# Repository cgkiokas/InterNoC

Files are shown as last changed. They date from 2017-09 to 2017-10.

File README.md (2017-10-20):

# InterNoC
InterNoC prototype board

### Description:
Nowadays, many embedded systems host a significant number of micro-controllers and processors (i.e. IoT devices, vehicles, airplanes, satellites) and as this number continues to increase, traditional bus solutions will start to fail on those platforms as well. Network-on-Chip (NoC) not only offer a scalable solution for MPSoC interconnects but they can also provide a uniform platform of communication to embedded systems with multiple interconnected devices.

This project aims to build an open-source FPGA-based NoC where devices can be connected to each other, transparently, enabling mixed protocol communication between multiple master / slave devices, without the need for a shared bus and at the same time allowing each device to operate in its own clock domain.

### Link to project page:
https://hackaday.io/project/27083-internoc

### Setup Notes:
All components are packed in InterNoC.lib & InterNoC.pretty so adding them in the component library and putting it in top priority should make the parts fully portable.

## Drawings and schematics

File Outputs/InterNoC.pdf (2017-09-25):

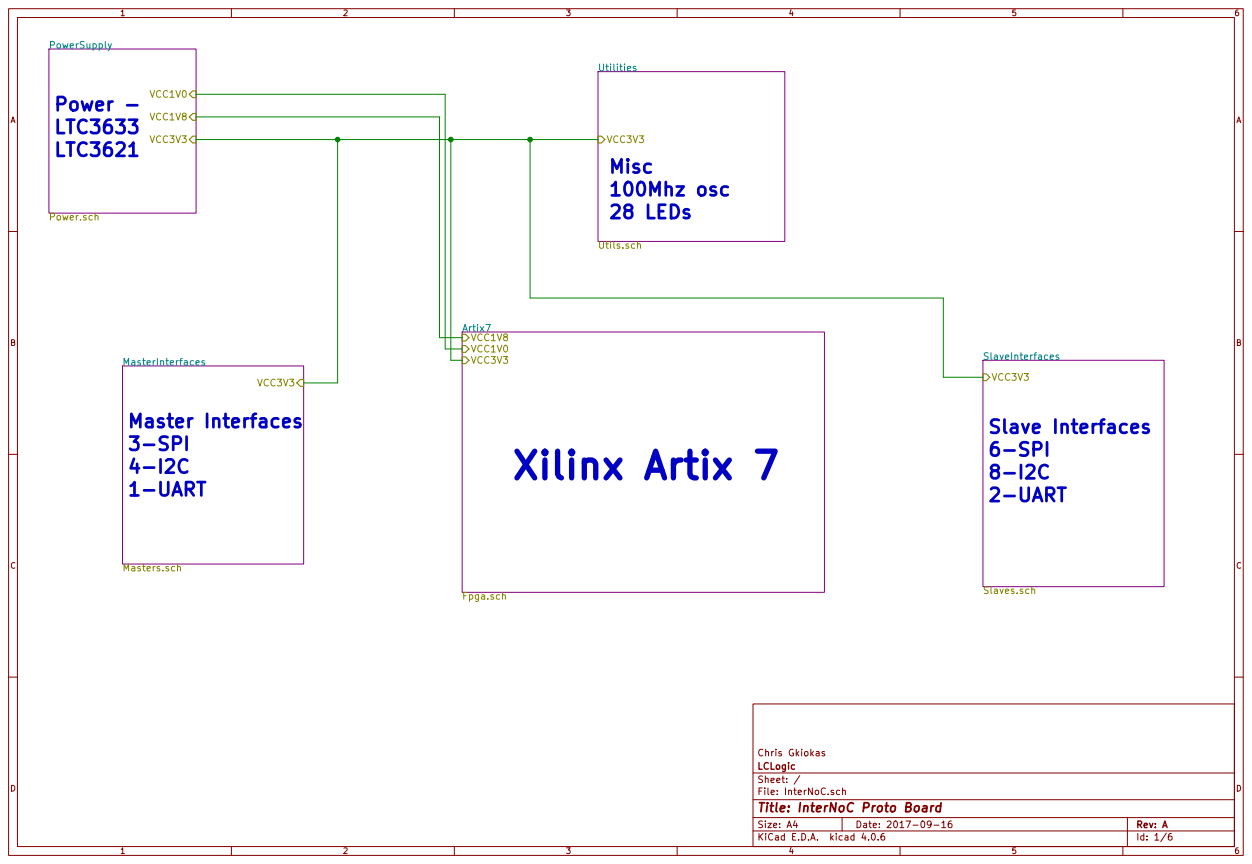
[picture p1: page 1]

Master Interfaces 4-I2C

Slave Interfaces 8-I2C

File: InterNoC.sch Sheet: / LCLogic Chris Gkiokas

Id: 1/6 Title: InterNoC Proto Board

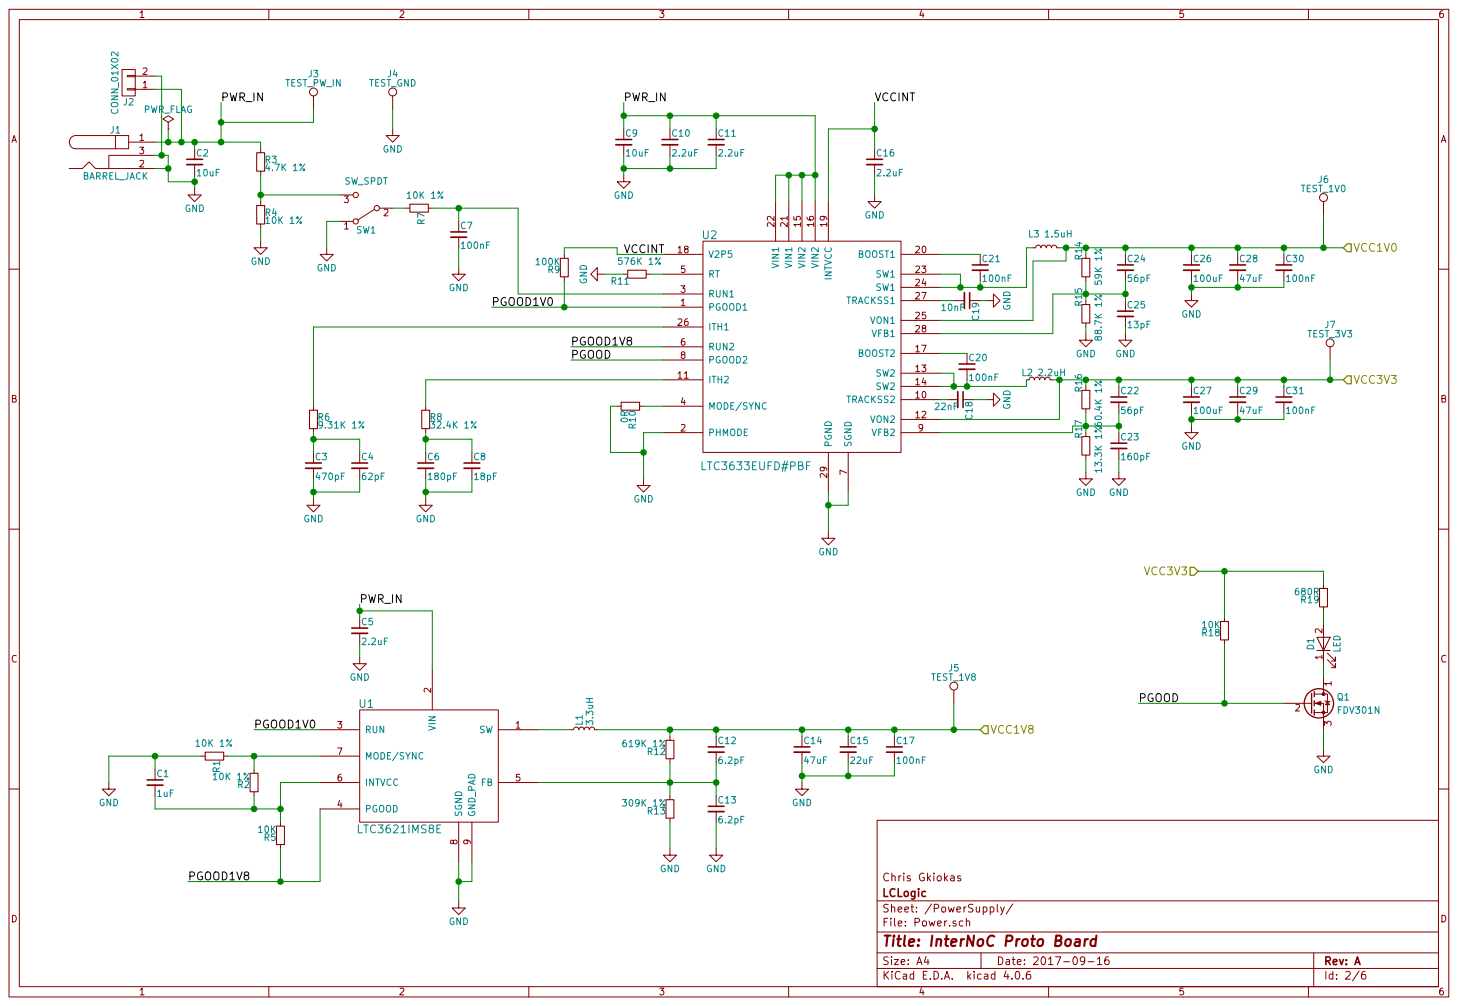
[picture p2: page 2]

File: Power.sch Sheet: /PowerSupply/
Id: 2/6 Title: InterNoC Proto Board

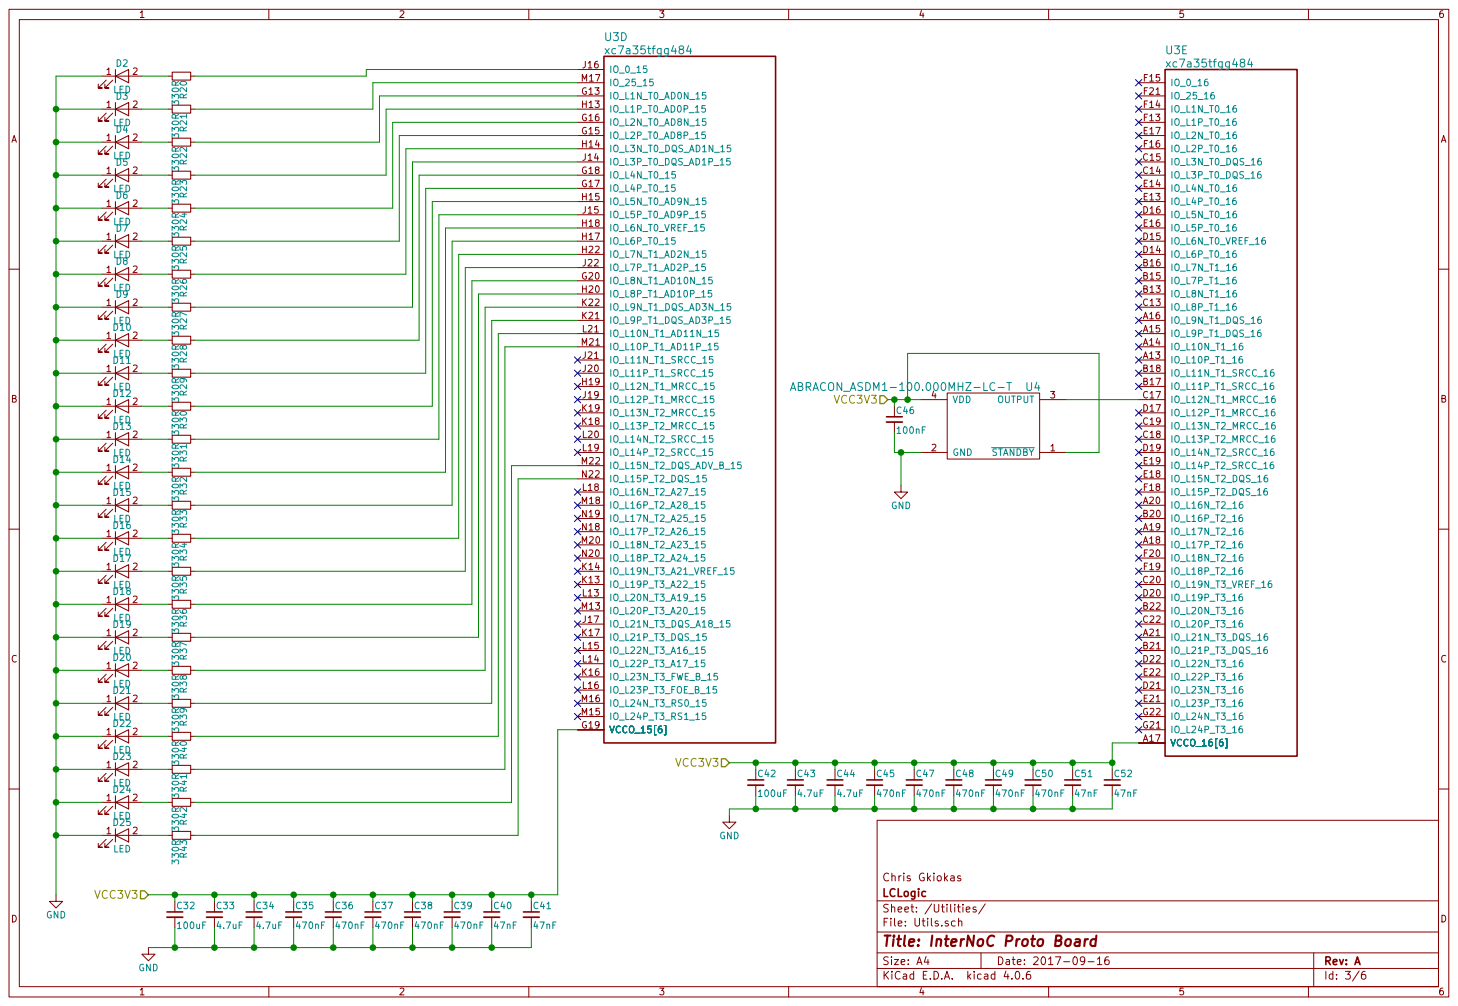
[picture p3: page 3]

File: Utils.sch Sheet: /Utilities/ LCLogic Chris Gkiokas

Id: 3/6 Title: InterNoC Proto Board

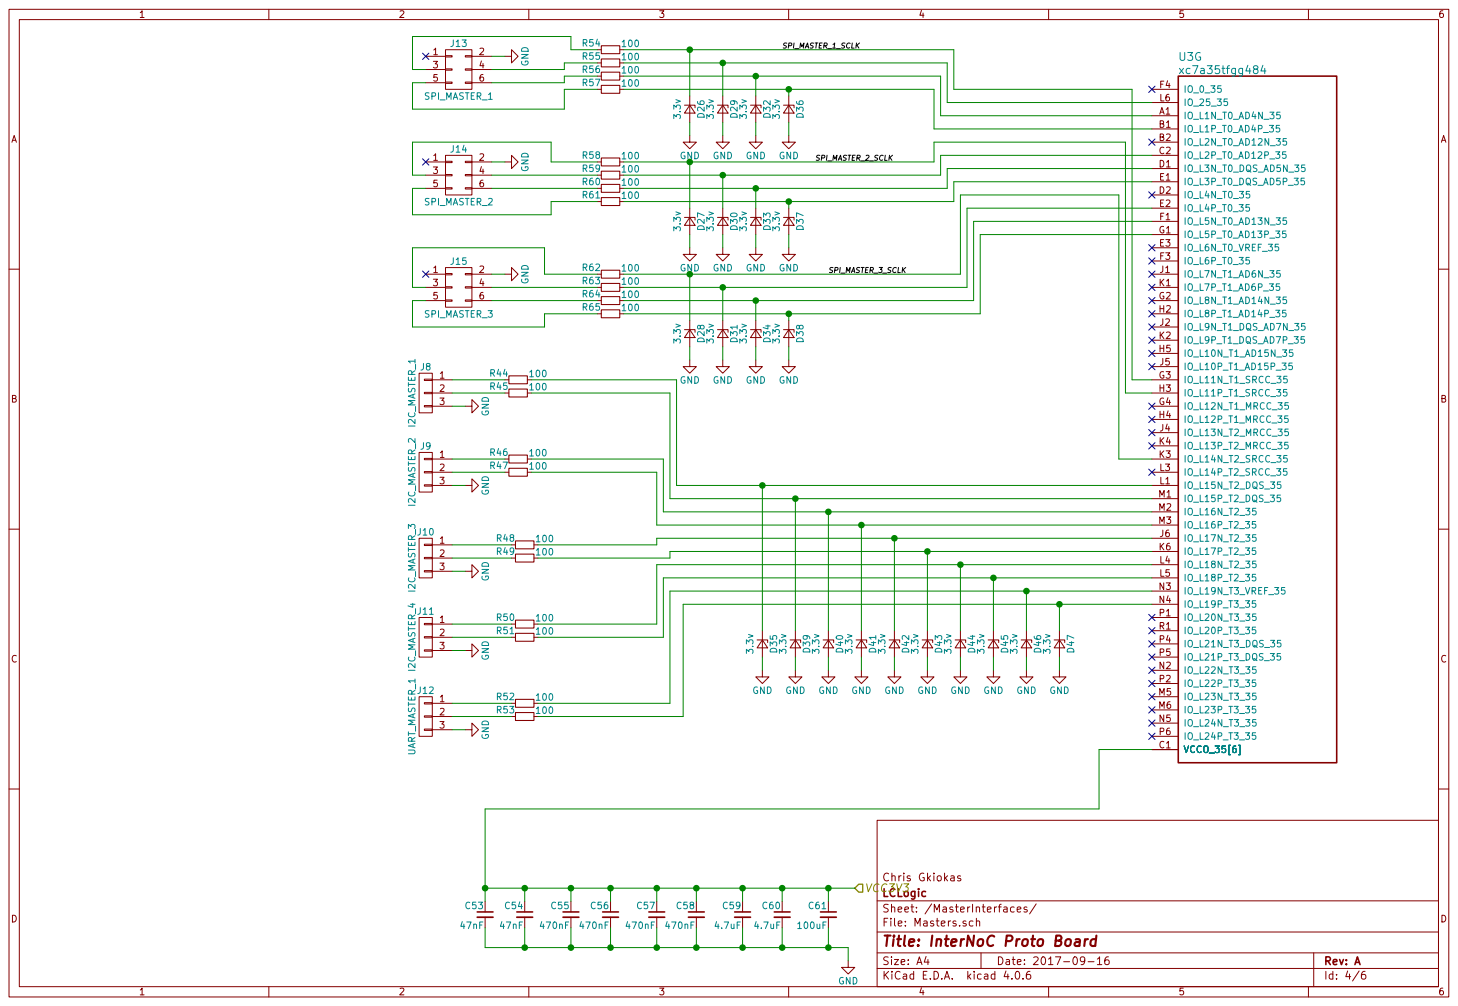
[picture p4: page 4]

IO_L1P_T0_AD4P_35 B1 VCCO_35[6] C1 IO_L6N_T0_VREF_35 E3 IO_L6P_T0_35 F3 IO_L7N_T1_AD6N_35 J1 IO_L7P_T1_AD6P_35 K1 IO_L8N_T1_AD14N_35 G2 IO_L8P_T1_AD14P_35 H2 IO_L9N_T1_DQS_AD7N_35 J2 IO_L9P_T1_DQS_AD7P_35 K2 IO_L10N_T1_AD15N_35 H5 IO_L10P_T1_AD15P_35 J5 IO_L11N_T1_SRCC_35 G3

IO_L3N_T0_DQS_AD5N_35 D1
IO_L3P_T0_DQS_AD5P_35 E1
IO_L4N_T0_35 D2

IO_L5N_T0_AD13N_35 F1
IO_L5P_T0_AD13P_35 G1

IO_L16N_T2_35 M2
IO_L16P_T2_35 M3
IO_L17N_T2_35 J6
IO_L17P_T2_35 K6

IO_L18P_T2_35 L5
IO_L19N_T3_VREF_35 N3
IO_L19P_T3_35 N4

File: Masters.sch Sheet: /MasterInterfaces/ LCLogic Chris Gkiokas

Id: 4/6 Title: InterNoC Proto Board

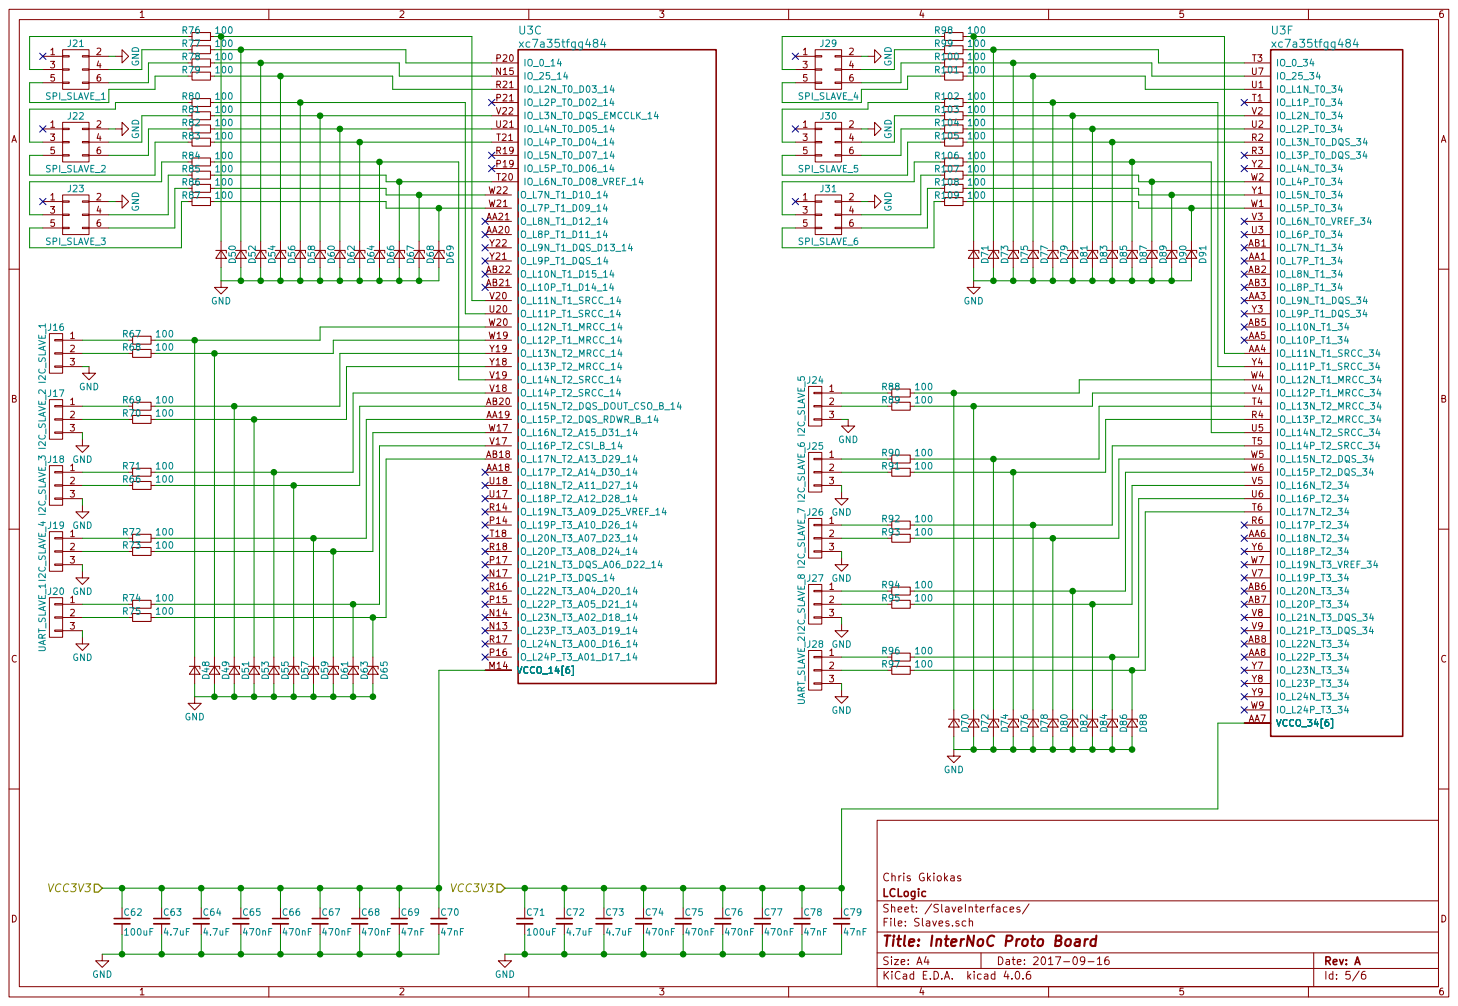
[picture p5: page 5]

IO_L5N_T0_34 Y1
IO_L5P_T0_34 W1

IO_L12P_T1_MRCC_34 V4
IO_L13N_T2_MRCC_34 T4
IO_L13P_T2_MRCC_34 R4

File: Slaves.sch Sheet: /SlaveInterfaces/ LCLogic Chris Gkiokas

Id: 5/6 Title: InterNoC Proto Board

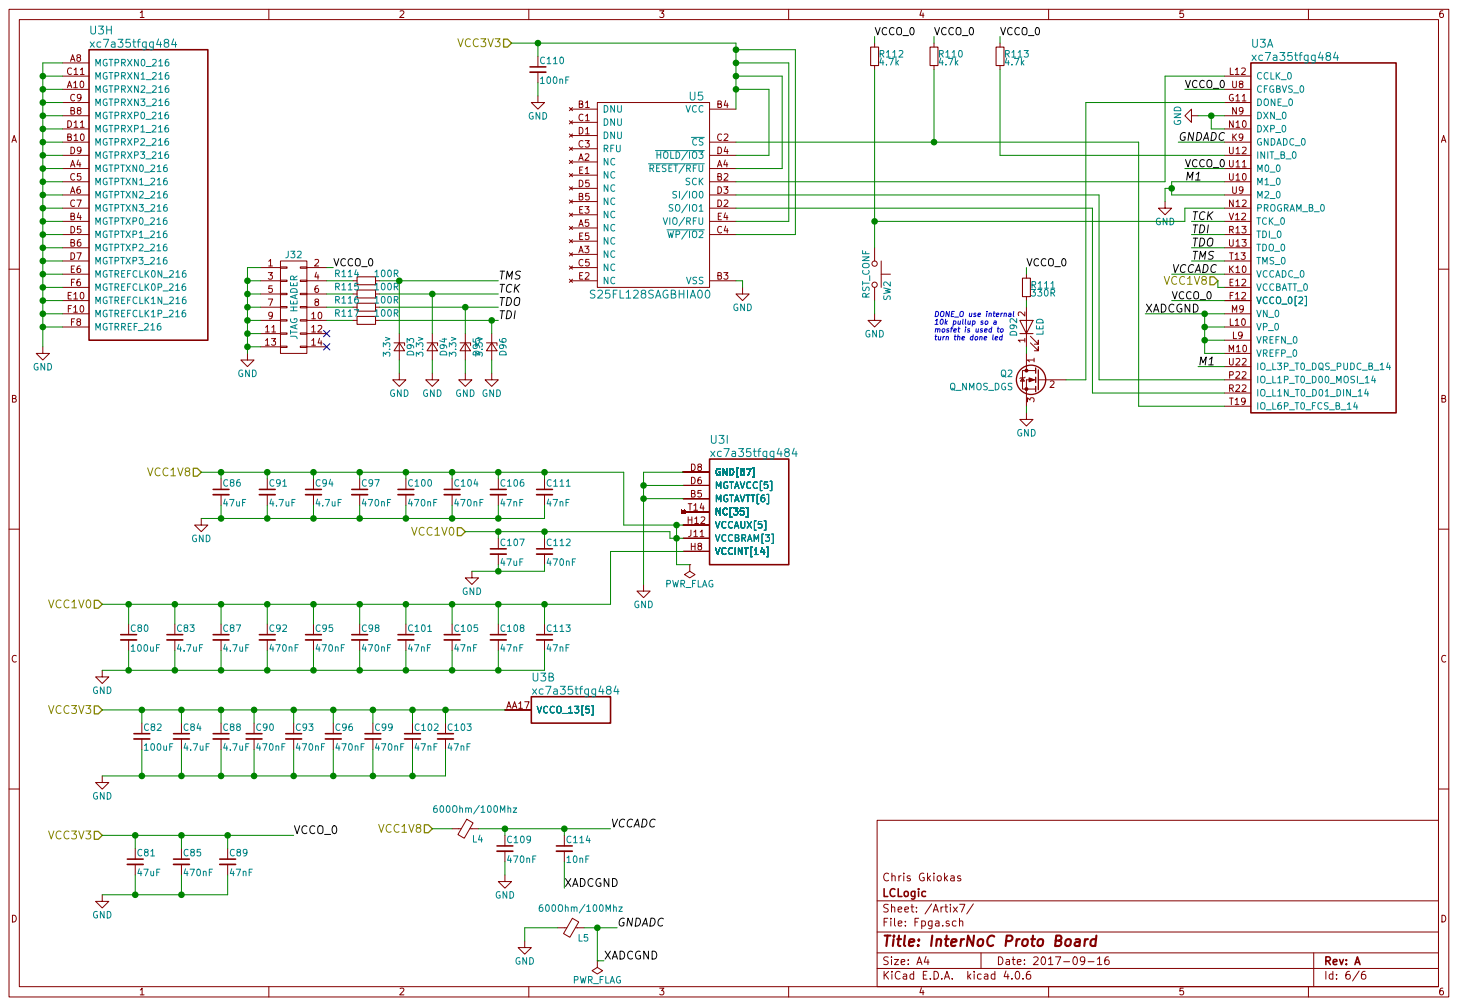
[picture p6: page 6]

DONE_O use internal 10k pullup so a mosfet is used to

turn the done led

File: Fpga.sch Sheet: /Artix7/ LCLogic Chris Gkiokas

Id: 6/6 Title: InterNoC Proto Board

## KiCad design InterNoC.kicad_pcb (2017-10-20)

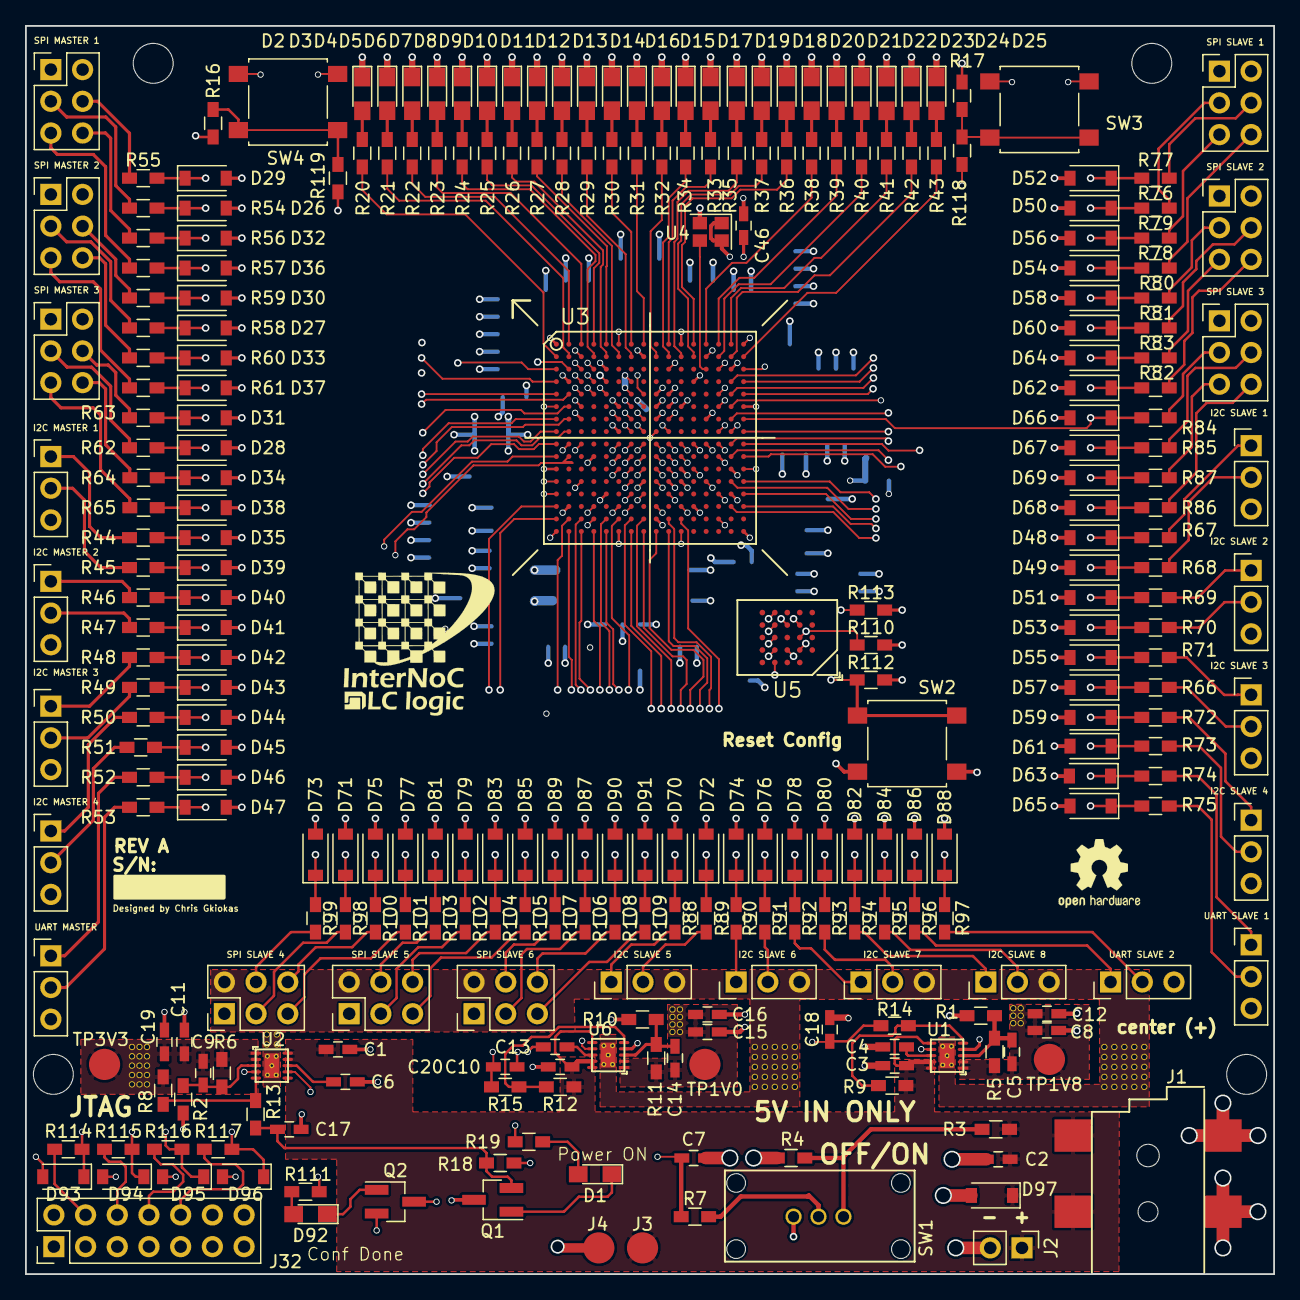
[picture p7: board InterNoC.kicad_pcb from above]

Board: 6 copper layers, 100.0 x 100.0 mm, 345 parts (0 on the bottom side), 226 nets.

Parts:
C1, C3, C8, C10, C11, C15: 10uF X5R; C_0603_HandSoldering
C2: 10uF; C_0603_HandSoldering
C4, C6, C13: 0.1uF; C_0603_HandSoldering
C5, C9, C14, C114: 10nF X5R; C_0603_HandSoldering
C7, C46, C110: 100nF; C_0603_HandSoldering
C12, C16, C19: 100nF X5R; C_0603_HandSoldering
C17: 220nF; C_0603_HandSoldering
C18, C20: 680nF; C_0603_HandSoldering
C21, C22, C23, C24, C80: 100uF X5R; C_1210_HandSoldering
C25, C26, C27, C28, C29, C30, C31, C32, C83, C87, C91, C94: 4.7uF X5R; C_0805_HandSoldering
C33, C34, C35, C36, C37, C38, C39, C40, C41, C42, C43, C44, C45, C47, C48, C49, C85, C92, C95, C97, C98, C100, C104, C109: 470nF X5R; C_0603_HandSoldering
C50, C51, C52, C53, C54, C55, C56, C57, C89, C101, C105, C106, C108, C111, C113: 47nF X5R; C_0603_HandSoldering
C81, C86: 47uF X5R; C_1210_HandSoldering
C107: 47uF; C_1210_HandSoldering
C112: 470nF; C_0603_HandSoldering
D1, D2, D3, D4, D5, D6, D7, D8, D9, D10, D11, D12, D13, D14, D15, D16, D17, D18, D19, D20, D21, D22, D23, D24, D25, D92: LED; LED_0805_HandSoldering
D26, D27, D28, D29, D30, D31, D32, D33, D34, D35, D36, D37, D38, D39, D40, D41, D42, D43, D44, D45, D46, D47, D48, D49, D50, D51, D52, D53, D54, D55, D56, D57, D58, D59, D60, D61, D62, D63, D64, D65, D66, D67, D68, D69, D70, D71, D72, D73, D74, D75, D76, D77, D78, D79, D80, D81, D82, D83, D84, D85, D86, D87, D88, D89, D90, D91, D93, D94, D95, D96: 3.3v; D_SOD-123
D97: 6v; D_SOD-123
I2C MASTER 1: I2C_MASTER_1; Pin_Header_Straight_1x03_Pitch2.54mm
I2C MASTER 2: I2C_MASTER_2; Pin_Header_Straight_1x03_Pitch2.54mm
I2C MASTER 3: I2C_MASTER_3; Pin_Header_Straight_1x03_Pitch2.54mm
I2C MASTER 4: I2C_MASTER_4; Pin_Header_Straight_1x03_Pitch2.54mm
I2C SLAVE 1: I2C_SLAVE_1; Pin_Header_Straight_1x03_Pitch2.54mm
I2C SLAVE 2: I2C_SLAVE_2; Pin_Header_Straight_1x03_Pitch2.54mm
I2C SLAVE 3: I2C_SLAVE_3; Pin_Header_Straight_1x03_Pitch2.54mm
I2C SLAVE 4: I2C_SLAVE_4; Pin_Header_Straight_1x03_Pitch2.54mm
I2C SLAVE 5: I2C_SLAVE_5; Pin_Header_Straight_1x03_Pitch2.54mm
I2C SLAVE 6: I2C_SLAVE_6; Pin_Header_Straight_1x03_Pitch2.54mm
I2C SLAVE 7: I2C_SLAVE_7; Pin_Header_Straight_1x03_Pitch2.54mm
I2C SLAVE 8: I2C_SLAVE_8; Pin_Header_Straight_1x03_Pitch2.54mm
J1: BARREL_JACK; PJ-002AH-SMT-TR
J2: CONN_01X02; Pin_Header_Straight_1x02_Pitch2.54mm
J3: TEST_PW_IN; test_point_single
J4: TEST_GND; test_point_single
J32: JTAG HEADER; Pin_Header_Straight_2x07_Pitch2.54mm
L4, L5: 600Ohm/100Mhz; L_0805_HandSoldering
Q1: FDV301N; SOT-23_Handsoldering
Q2: Q_NMOS_DGS; SOT-23_Handsoldering
R1: 1.5K 1%; R_0603_HandSoldering
R2: 1.15K 1%; R_0603_HandSoldering
R3, R4, R7, R16, R17, R18, R118, R119: 10K; R_0603_HandSoldering
R5: 1.87K 1%; R_0603_HandSoldering
R6: 3.57K 1%; R_0603_HandSoldering
R8: 20K; R_0603_HandSoldering
R9, R12: 56K; R_0603_HandSoldering
R10: 10.2K 1%; R_0603_HandSoldering
R11: 2.55K 1%; R_0603_HandSoldering
R13, R14, R15: 4.7K; R_0603_HandSoldering
R19: 680R; R_0603_HandSoldering
R20, R21, R22, R23, R24, R25, R26, R27, R28, R29, R30, R31, R32, R33, R34, R35, R36, R37, R38, R39, R40, R41, R42, R43, R111: 330R; R_0603_HandSoldering
R44, R45, R46, R47, R48, R49, R50, R51, R52, R53, R54, R55, R56, R57, R58, R59, R60, R61, R62, R63, R64, R65, R66, R67, R68, R69, R70, R71, R72, R73, R74, R75, R76, R77, R78, R79, R80, R81, R82, R83, R84, R85, R86, R87, R88, R89, R90, R91, R92, R93, R94, R95, R96, R97, R98, R99, R100, R101, R102, R103, R104, R105, R106, R107, R108, R109, R114, R115, R116, R117: 200; R_0603_HandSoldering
R110, R112, R113: 4.7k; R_0603_HandSoldering
SPI MASTER 1: SPI_MASTER_1; Pin_Header_Straight_2x03_Pitch2.54mm
SPI MASTER 2: SPI_MASTER_2; Pin_Header_Straight_2x03_Pitch2.54mm
SPI MASTER 3: SPI_MASTER_3; Pin_Header_Straight_2x03_Pitch2.54mm
SPI SLAVE 1: SPI_SLAVE_1; Pin_Header_Straight_2x03_Pitch2.54mm
SPI SLAVE 2 : SPI_SLAVE_2; Pin_Header_Straight_2x03_Pitch2.54mm
SPI SLAVE 3: SPI_SLAVE_3; Pin_Header_Straight_2x03_Pitch2.54mm
SPI SLAVE 4: SPI_SLAVE_4; Pin_Header_Straight_2x03_Pitch2.54mm
SPI SLAVE 5: SPI_SLAVE_5; Pin_Header_Straight_2x03_Pitch2.54mm
SPI SLAVE 6: SPI_SLAVE_6; Pin_Header_Straight_2x03_Pitch2.54mm
SW1: SW_SPDT; MSS120004
SW2: RST_CONF; SW_SPST_B3S-1000
SW3, SW4: SW_Push; SW_SPST_B3S-1000
TP1V0: TEST_1V0; test_point_single
TP1V8: TEST_1V8; test_point_single
TP3V3: TEST_3V3; test_point_single
U1, U6: TPS7A9101DSKT
U2: TPS7A9201DSKR
U3: xc7a35tftg256; XC7A35T-1FTG256C
U4: ABRACON_ASDM1-100.000MHZ-LC-T; Crystal_SMD_2520-4pin_2.5x2.0mm
U5: S25FL128SAGBHIA00
UART MASTER : UART_MASTER_1; Pin_Header_Straight_1x03_Pitch2.54mm
UART SLAVE 1: UART_SLAVE_1; Pin_Header_Straight_1x03_Pitch2.54mm
UART SLAVE 2: UART_SLAVE_2; Pin_Header_Straight_1x03_Pitch2.54mm

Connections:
/Artix7/GNDADC: C114.2, L5.1, U3.G7, U3.H7, U3.H8, U3.J7, U3.J8
/Artix7/TCK: D94.1, R115.2, U3.L7
/Artix7/TDI: D96.1, R117.2, U3.N7
/Artix7/TDO: D95.1, R116.2, U3.N8
/Artix7/TMS: D93.1, R114.2, U3.M7
/Artix7/VCC1V0: C14.1, C15.1, C16.1, C80.1, C83.1, C87.1, C92.1, C95.1, C98.1, C101.1, C105.1, C107.1, C108.1, C112.1, C113.1, R11.1, TP1V0.1, U3.E10, U3.F7, U3.F9, U3.F11, U3.G6, U3.H9, U3.J6, U3.K9, U3.L8, U6.1, U6.2
/Artix7/VCC1V8: C5.1, C8.1, C12.1, C86.1, C91.1, C94.1, C97.1, C100.1, C104.1, C106.1, C111.1, L4.2, R5.1, TP1V8.1, U1.1, U1.2, U3.F8, U3.G10, U3.J10, U3.K11, U3.L10
/Artix7/VCC3V3: C9.1, C11.1, C19.1, C21.1, C22.1, C23.1, C24.1, C25.1, C26.1, C27.1, C28.1, C29.1, C30.1, C31.1, C32.1, C33.1, C34.1, C35.1, C36.1, C37.1, C38.1, C39.1, C40.1, C41.1, C42.1, C43.1, C44.1, C45.1, C46.1, C47.1, C48.1, C49.1, C50.1, C51.1, C52.1, C53.1, C54.1, C55.1, C56.1, C57.1, C81.1, C85.1, C89.1, C110.1, J32.2, R6.1, R8.2, R18.2, R19.2, R110.1, R111.1, R112.1, R113.1, SW3.1, SW4.1, TP3V3.1, U2.1, U2.2, U3.A6, U3.A16, U3.B3, U3.B13, U3.C10, U3.D7, U3.E4, U3.E7, U3.E14, U3.F1, U3.H15, U3.J2, U3.J12, U3.L6, U3.L16, U3.M3, U3.M9, U3.M13, U3.N10, U3.P7, U3.R4, U3.R14, U3.T1, U3.T11, U4.1, U4.4, U5.A4, U5.B4, U5.C4, U5.D4, U5.E4
/Artix7/VCCADC: C109.1, C114.1, L4.1, U3.G8
/PowerSupply/PGOOD: C17.1, Q1.2, R13.2, R18.1
/PowerSupply/PGOOD1V0: C20.1, R15.2, U1.7
/PowerSupply/PGOOD1V8: C18.1, R14.2, U2.7
/PowerSupply/PWR_IN: C1.1, C2.1, C3.1, C10.1, D97.1, J1.1, J2.1, J3.1, R3.1, R9.2, R12.2, U1.6, U1.9, U1.10, U2.6, U2.9, U2.10, U6.6, U6.9, U6.10
CLOCK: U3.C13, U4.3
GND: C1.2, C2.2, C3.2, C4.2, C6.2, C7.2, C8.2, C10.2, C11.2, C12.2, C13.2, C15.2, C16.2, C17.2, C18.2, C19.2, C20.2, C21.2, C22.2, C23.2, C24.2, C25.2, C26.2, C27.2, C28.2, C29.2, C30.2, C31.2, C32.2, C33.2, C34.2, C35.2, C36.2, C37.2, C38.2, C39.2, C40.2, C41.2, C42.2, C43.2, C44.2, C45.2, C46.2, C47.2, C48.2, C49.2, C50.2, C51.2, C52.2, C53.2, C54.2, C55.2, C56.2, C57.2, C80.2, C81.2, C83.2, C85.2, C86.2, C87.2, C89.2, C91.2, C92.2, C94.2, C95.2, C97.2, C98.2, C100.2, C101.2, C104.2, C105.2, C106.2, C107.2, C108.2, C109.2, C110.2, C111.2, C112.2, C113.2, D2.1, D3.1, D4.1, D5.1, D6.1, D7.1, D8.1, D9.1, D10.1, D11.1, D12.1, D13.1, D14.1, D15.1, D16.1, D17.1, D18.1, D19.1, D20.1, D21.1, D22.1, D23.1, D24.1, D25.1, D26.2, D27.2, D28.2, D29.2, D30.2, D31.2, D32.2, D33.2, D34.2, D35.2, D36.2, D37.2, D38.2, D39.2, D40.2, D41.2, D42.2, D43.2, D44.2, D45.2, D46.2, D47.2, D48.2, D49.2, D50.2, D51.2, D52.2, D53.2, D54.2, D55.2, D56.2, D57.2, D58.2, D59.2, D60.2, D61.2, D62.2, D63.2, D64.2, D65.2, D66.2, D67.2, D68.2, D69.2, D70.2, D71.2, D72.2, D73.2, D74.2, D75.2, D76.2, D77.2, D78.2, D79.2, D80.2, D81.2, D82.2, D83.2, D84.2, D85.2, D86.2, D87.2, D88.2, D89.2, D90.2, D91.2, D93.2, D94.2, D95.2, D96.2, D97.2, I2C MASTER 1.3, I2C MASTER 2.3, I2C MASTER 3.3, I2C MASTER 4.3, I2C SLAVE 1.3, I2C SLAVE 2.3, I2C SLAVE 3.3, I2C SLAVE 4.3, I2C SLAVE 5.3, I2C SLAVE 6.3, I2C SLAVE 7.3, I2C SLAVE 8.3, J1.2, J1.3, J2.2, J4.1, J32.1, J32.3, J32.5, J32.7, J32.9, J32.11, J32.13, L5.2, Q1.3, Q2.3, R1.1, R2.1, R4.2, R10.1, R16.1, R17.1, SPI MASTER 1.2, SPI MASTER 2.2, SPI MASTER 3.2, SPI SLAVE 1.2, SPI SLAVE 2.2, SPI SLAVE 3.2, SPI SLAVE 4.2, SPI SLAVE 5.2, SPI SLAVE 6.2, SW1.1, SW2.2, U1.4, U1.11, U2.4, U2.11, U3.A1, U3.A11, U3.B8, U3.C5, U3.C15, U3.D2, U3.D12, U3.E9, U3.F6, U3.F10, U3.F16, U3.G3, U3.G9, U3.G13, U3.H6, U3.J9, U3.J11, U3.K4, U3.K6, U3.K7, U3.K8, U3.K14, U3.L1, U3.L11, U3.L15, U3.M8, U3.M10, U3.M11, U3.N5, U3.N15, U3.P2, U3.P12, U3.R9, U3.T6, U3.T16, U4.2, U5.B3, U6.4, U6.11, UART MASTER.3, UART SLAVE 1.3, UART SLAVE 2.3
GP_BTN_1: R118.1, U3.M1
GP_BTN_2: R119.1, U3.N1
I2C_MASTER_1_SCL: D39.1, R45.2, U3.F3
I2C_MASTER_1_SDA: D35.1, R44.2, U3.F2
I2C_MASTER_2_SCL: D41.1, R47.2, U3.G2
I2C_MASTER_2_SDA: D40.1, R46.2, U3.G1
I2C_MASTER_3_SCL: D43.1, R49.2, U3.H2
I2C_MASTER_3_SDA: D42.1, R48.2, U3.H1
I2C_MASTER_4_SCL: D45.1, R51.2, U3.J3
I2C_MASTER_4_SDA: D44.1, R50.2, U3.J1
I2C_SLAVE_1_SCL: D49.1, R68.1, U3.J15
I2C_SLAVE_1_SDA: D48.1, R67.1, U3.J16
I2C_SLAVE_2_SCL: D53.1, R70.1, U3.K15
I2C_SLAVE_2_SDA: D51.1, R69.1, U3.K16
I2C_SLAVE_3_SCL: D57.1, R66.1, U3.M15
I2C_SLAVE_3_SDA: D55.1, R71.1, U3.M16
I2C_SLAVE_4_SCL: D61.1, R73.1, U3.N14
I2C_SLAVE_4_SDA: D59.1, R72.1, U3.N16
I2C_SLAVE_5_SCL: D72.1, R89.1, U3.R7
I2C_SLAVE_5_SDA: D70.1, R88.1, U3.T7
I2C_SLAVE_6_SCL: D76.1, R91.1, U3.R8
I2C_SLAVE_6_SDA: D74.1, R90.1, U3.T8
I2C_SLAVE_7_SCL: D80.1, R93.1, U3.P9
I2C_SLAVE_7_SDA: D78.1, R92.1, U3.T9
I2C_SLAVE_8_SCL: D84.1, R95.1, U3.R10
I2C_SLAVE_8_SDA: D82.1, R94.1, U3.T10
LED_1: R20.1, U3.B1
LED_2: R21.1, U3.B2
LED_3: R22.1, U3.A2
LED_4: R23.1, U3.A3
LED_5: R24.1, U3.B4
LED_6: R25.1, U3.A4
LED_7: R26.1, U3.B5
LED_8: R27.1, U3.A5
LED_9: R28.1, U3.B6
LED_10: R29.1, U3.B7
LED_11: R30.1, U3.A7
LED_12: R31.1, U3.A8
LED_13: R32.1, U3.B9
LED_14: R33.1, U3.A10
LED_15: R34.1, U3.B10
LED_16: R35.1, U3.B11
LED_17: R36.1, U3.A12
LED_18: R37.1, U3.B12
LED_19: R38.1, U3.A13
LED_20: R39.1, U3.A14
LED_21: R40.1, U3.B14
LED_22: R41.1, U3.A15
LED_23: R42.1, U3.B15
LED_24: R43.1, U3.B16
unnamed: C4.1, U1.8
unnamed: C5.2, R1.2, R5.2, U1.3
unnamed: C6.1, U2.8
unnamed: C7.1, R7.1, U6.7
unnamed: C9.2, R2.2, R6.2, U2.3
unnamed: C13.1, U6.8
unnamed: C14.2, R10.2, R11.2, U6.3
unnamed: D1.1, Q1.1
unnamed: D1.2, R19.1
unnamed: D2.2, R20.2
unnamed: D3.2, R21.2
unnamed: D4.2, R22.2
unnamed: D5.2, R23.2
unnamed: D6.2, R24.2
unnamed: D7.2, R25.2
unnamed: D8.2, R26.2
unnamed: D9.2, R27.2
unnamed: D10.2, R28.2
unnamed: D11.2, R29.2
unnamed: D12.2, R30.2
unnamed: D13.2, R31.2
unnamed: D14.2, R32.2
unnamed: D15.2, R33.2
unnamed: D16.2, R34.2
unnamed: D17.2, R35.2
unnamed: D18.2, R36.2
unnamed: D19.2, R37.2
unnamed: D20.2, R38.2
unnamed: D21.2, R39.2
unnamed: D22.2, R40.2
unnamed: D23.2, R41.2
unnamed: D24.2, R42.2
unnamed: D25.2, R43.2
unnamed: D92.1, Q2.1
unnamed: D92.2, R111.2
unnamed: I2C MASTER 1.1, R44.1
unnamed: I2C MASTER 1.2, R45.1
unnamed: I2C MASTER 2.1, R46.1
unnamed: I2C MASTER 2.2, R47.1
unnamed: I2C MASTER 3.1, R48.1
unnamed: I2C MASTER 3.2, R49.1
unnamed: I2C MASTER 4.1, R50.1
unnamed: I2C MASTER 4.2, R51.1
unnamed: R52.1, UART MASTER.1
unnamed: R53.1, UART MASTER.2
unnamed: R54.1, SPI MASTER 1.3
unnamed: R55.1, SPI MASTER 1.4
unnamed: R57.1, SPI MASTER 1.5
unnamed: R56.1, SPI MASTER 1.6
unnamed: R58.1, SPI MASTER 2.3
unnamed: R59.1, SPI MASTER 2.4
unnamed: R61.1, SPI MASTER 2.5
unnamed: R60.1, SPI MASTER 2.6
unnamed: R62.1, SPI MASTER 3.3
unnamed: R63.1, SPI MASTER 3.4
unnamed: R65.1, SPI MASTER 3.5
unnamed: R64.1, SPI MASTER 3.6
unnamed: I2C SLAVE 1.1, R67.2
unnamed: I2C SLAVE 1.2, R68.2
unnamed: I2C SLAVE 2.1, R69.2
unnamed: I2C SLAVE 2.2, R70.2
unnamed: I2C SLAVE 3.1, R71.2
unnamed: I2C SLAVE 3.2, R66.2
unnamed: I2C SLAVE 4.1, R72.2
unnamed: I2C SLAVE 4.2, R73.2
unnamed: R74.2, UART SLAVE 1.1
unnamed: R75.2, UART SLAVE 1.2
unnamed: R76.2, SPI SLAVE 1.3
unnamed: R77.2, SPI SLAVE 1.4
unnamed: R79.2, SPI SLAVE 1.5
unnamed: R78.2, SPI SLAVE 1.6
unnamed: R80.2, SPI SLAVE 2.3
unnamed: R81.2, SPI SLAVE 2.4
unnamed: R83.2, SPI SLAVE 2.5
unnamed: R82.2, SPI SLAVE 2.6
unnamed: R84.2, SPI SLAVE 3.3
unnamed: R85.2, SPI SLAVE 3.4
unnamed: R87.2, SPI SLAVE 3.5
unnamed: R86.2, SPI SLAVE 3.6
unnamed: I2C SLAVE 5.1, R88.2
unnamed: I2C SLAVE 5.2, R89.2
unnamed: I2C SLAVE 6.1, R90.2
unnamed: I2C SLAVE 6.2, R91.2
unnamed: I2C SLAVE 7.1, R92.2
unnamed: I2C SLAVE 7.2, R93.2
unnamed: I2C SLAVE 8.1, R94.2
unnamed: I2C SLAVE 8.2, R95.2
unnamed: R96.2, UART SLAVE 2.1
unnamed: R97.2, UART SLAVE 2.2
unnamed: R98.2, SPI SLAVE 4.3
unnamed: R99.2, SPI SLAVE 4.4
unnamed: R101.2, SPI SLAVE 4.5
unnamed: R100.2, SPI SLAVE 4.6
unnamed: R102.2, SPI SLAVE 5.3
unnamed: R103.2, SPI SLAVE 5.4
unnamed: R105.2, SPI SLAVE 5.5
unnamed: R104.2, SPI SLAVE 5.6
unnamed: R106.2, SPI SLAVE 6.3
unnamed: R107.2, SPI SLAVE 6.4
unnamed: R109.2, SPI SLAVE 6.5
unnamed: R108.2, SPI SLAVE 6.6
unnamed: J32.4, R114.1
unnamed: J32.6, R115.1
unnamed: J32.8, R116.1
unnamed: J32.10, R117.1
unnamed: Q2.2, U3.H10
unnamed: R3.2, R4.1, SW1.3
unnamed: R7.2, SW1.2
unnamed: R12.1, R15.1, U6.5
unnamed: R8.1, R13.1, U2.5
unnamed: R9.1, R14.1, U1.5
unnamed: R110.2, U3.L12, U5.C2
unnamed: R112.2, SW2.1, U3.L9
unnamed: R113.2, U3.K10
unnamed: R17.2, R118.2, SW3.2
unnamed: R16.2, R119.2, SW4.2
unnamed: U3.E8, U5.B2
unnamed: U3.J13, U5.D3
unnamed: U3.J14, U5.D2
SPI_MASTER_1_CS: D36.1, R57.2, U3.C1
SPI_MASTER_1_MISO: D32.1, R56.2, U3.C2
SPI_MASTER_1_MOSI: D29.1, R55.2, U3.C4
SPI_MASTER_1_SCLK: D26.1, R54.2, U3.C3
SPI_MASTER_2_CS: D37.1, R61.2, U3.D5
SPI_MASTER_2_MISO: D33.1, R60.2, U3.D1
SPI_MASTER_2_MOSI: D30.1, R59.2, U3.D3
SPI_MASTER_2_SCLK: D27.1, R58.2, U3.D4
SPI_MASTER_3_CS: D38.1, R65.2, U3.E5
SPI_MASTER_3_MISO: D34.1, R64.2, U3.E3
SPI_MASTER_3_MOSI: D31.1, R63.2, U3.E1
SPI_MASTER_3_SCLK: D28.1, R62.2, U3.E2
SPI_SLAVE_1_CS: D56.1, R79.1, U3.D15
SPI_SLAVE_1_MISO: D54.1, R78.1, U3.D16
SPI_SLAVE_1_MOSI: D52.1, R77.1, U3.C14
SPI_SLAVE_1_SCLK: D50.1, R76.1, U3.C16
SPI_SLAVE_2_CS: D64.1, R83.1, U3.F14
SPI_SLAVE_2_MISO: D62.1, R82.1, U3.F15
SPI_SLAVE_2_MOSI: D60.1, R81.1, U3.E16
SPI_SLAVE_2_SCLK: D58.1, R80.1, U3.E15
SPI_SLAVE_3_CS: D69.1, R87.1, U3.H16
SPI_SLAVE_3_MISO: D68.1, R86.1, U3.H14
SPI_SLAVE_3_MOSI: D67.1, R85.1, U3.G15
SPI_SLAVE_3_SCLK: D66.1, R84.1, U3.G16
SPI_SLAVE_4_CS: D77.1, R101.1, U3.T2
SPI_SLAVE_4_MISO: D75.1, R100.1, U3.R2
SPI_SLAVE_4_MOSI: D73.1, R99.1, U3.R1
SPI_SLAVE_4_SCLK: D71.1, R98.1, U3.P1
SPI_SLAVE_5_CS: D85.1, R105.1, U3.T4
SPI_SLAVE_5_MISO: D83.1, R104.1, U3.P4
SPI_SLAVE_5_MOSI: D81.1, R103.1, U3.T3
SPI_SLAVE_5_SCLK: D79.1, R102.1, U3.R3
SPI_SLAVE_6_CS: D91.1, R109.1, U3.P6
SPI_SLAVE_6_MISO: D90.1, R108.1, U3.R6
SPI_SLAVE_6_MOSI: D89.1, R107.1, U3.T5
SPI_SLAVE_6_SCLK: D87.1, R106.1, U3.R5
UART_MASTER_1_RX: D47.1, R53.2, U3.K2
UART_MASTER_1_TX: D46.1, R52.2, U3.K1
UART_SLAVE_1_RX: D65.1, R75.1, U3.P15
UART_SLAVE_1_TX: D63.1, R74.1, U3.P16
UART_SLAVE_2_RX: D88.1, R97.1, U3.P11
UART_SLAVE_2_TX: D86.1, R96.1, U3.R11

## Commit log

2017-09-21 schematic ready commit
    first completed schematic commit
    [Fpga.sch, InterNoC.sch, Masters.sch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]
2017-09-25 Altered power supply from switcher to ldo's
    [Fpga.sch, InterNoC.sch, Masters.sch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]
2017-09-28 before layout commit
    [Fpga.sch, InterNoC.sch, Masters.sch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]
2017-10-02 fixed spi loc
    [InterNoC.kicad_pcb]
2017-10-07 pcb complete commit
    the layout is complete. NOT checked & verified
    [Fpga.sch, InterNoC.kicad_pcb, InterNoC.sch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]
2017-10-10 layout finalizing
    drc complete
    [Fpga.sch, InterNoC.kicad_pcb, InterNoC.sch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]
